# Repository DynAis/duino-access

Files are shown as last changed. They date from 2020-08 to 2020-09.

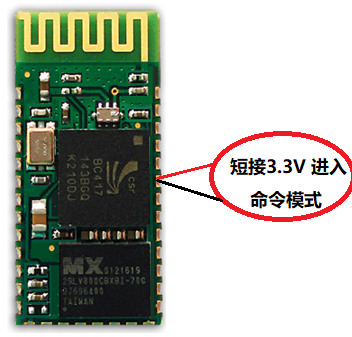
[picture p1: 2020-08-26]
doc/XM-04-HID蓝牙HID模块/命令模式.png

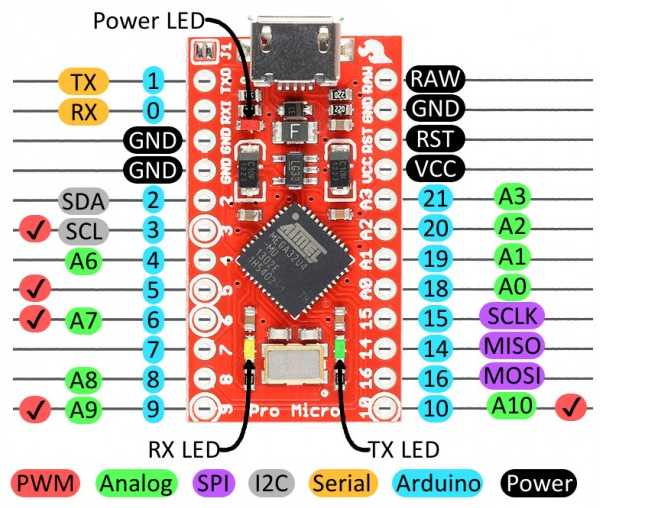
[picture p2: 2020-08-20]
doc/Arduino-Pro-Micro/引脚图.jpg

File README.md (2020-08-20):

# duino-access
 arduino based finger-print access system 

## 后续开发

### 库HN610

| 文件名 | 内容 |
| --- | --- |
| auth | 通讯签名算法(默认不签名) |
| fp | 大部分能直接用的API |
| fpmComm | 模块命令API |
| hzDevice  | 串口通信底层 |
| pinDef | 主板引脚定义 |
| hzTypes | 数据类型定义 |

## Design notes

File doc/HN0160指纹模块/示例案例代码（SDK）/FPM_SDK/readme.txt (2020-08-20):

####################################
#### HOZONOVO ALL RIGHTS RESERVED ####
####################################

fpmSDK implement note:

essential files need to be implemented:
fpmComm.c
fpmComm.h
hzTypes.h
hzDevice.c
hzDevice.h

Only 4 functions (in hzDevice) required to implement the protocol:

1)void write(const UINT8 *data, UINT32 len);	//send out data through UART port

2)UINT8 receive(UINT8 *data, UINT32 *len);	//receive data from fpm with UART

3)UINT32 getEndTime(UINT32 time);	//gets the expected ending timer tick in ms unit

4)UINT32 getCurTime(void);	//gets the current timer tick in ms unit

If bidirectional signature verification is required, there is another function that needs to be implemented:
5）void genRandom(UINT8 *ramdom,UINT8 len) // gen random number for signature

referenece files to realize the basic fingerprint functions:
fp.c
fp.h

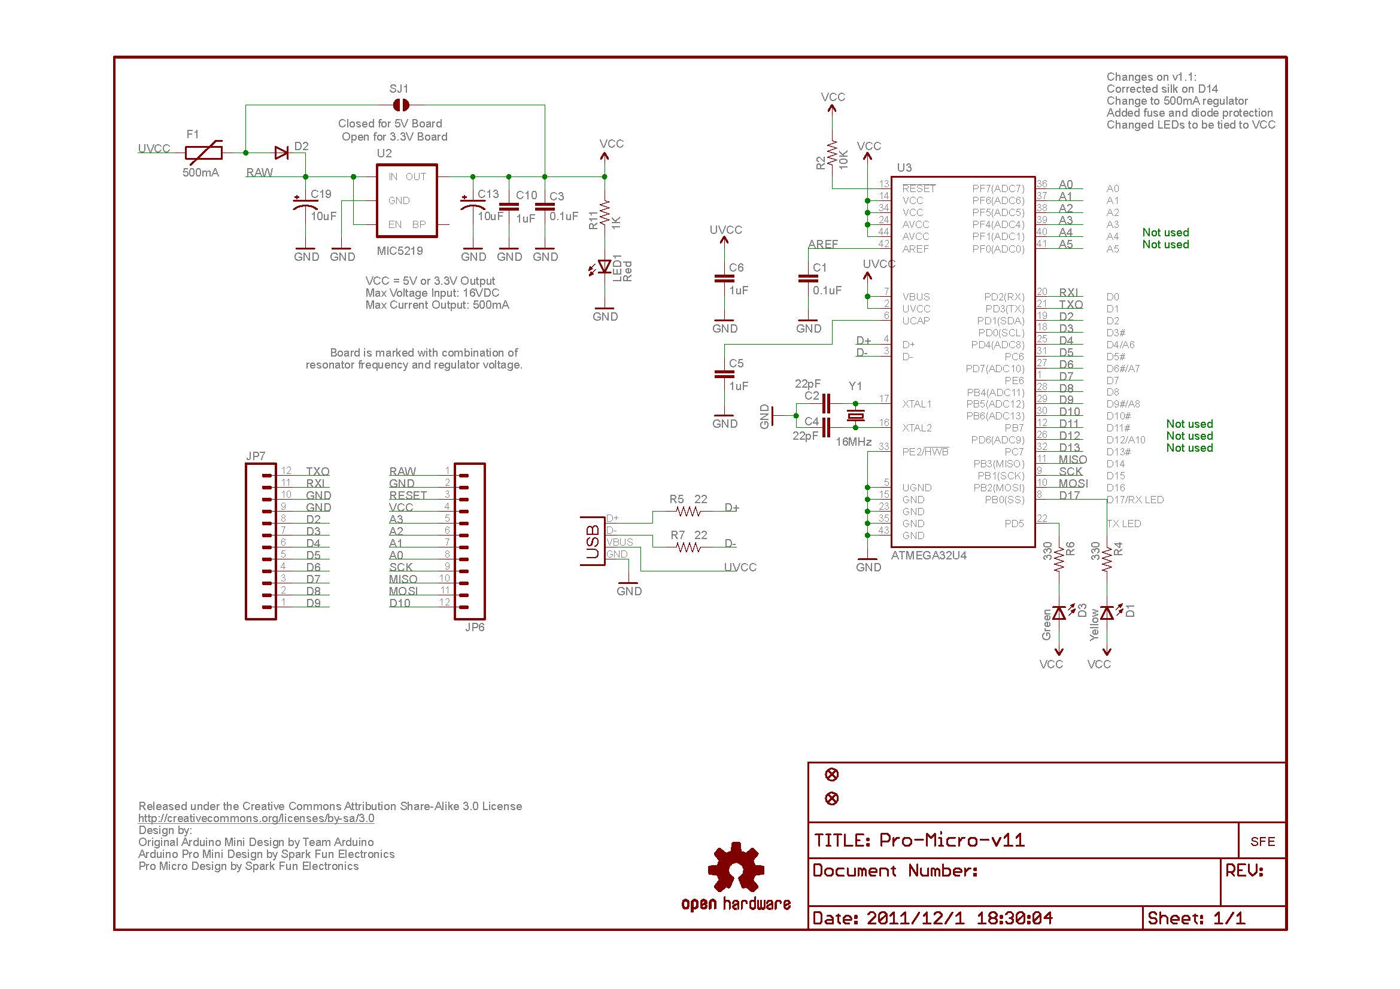
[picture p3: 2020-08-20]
doc/Arduino-Pro-Micro/Pro-Micro-原理图.jpg

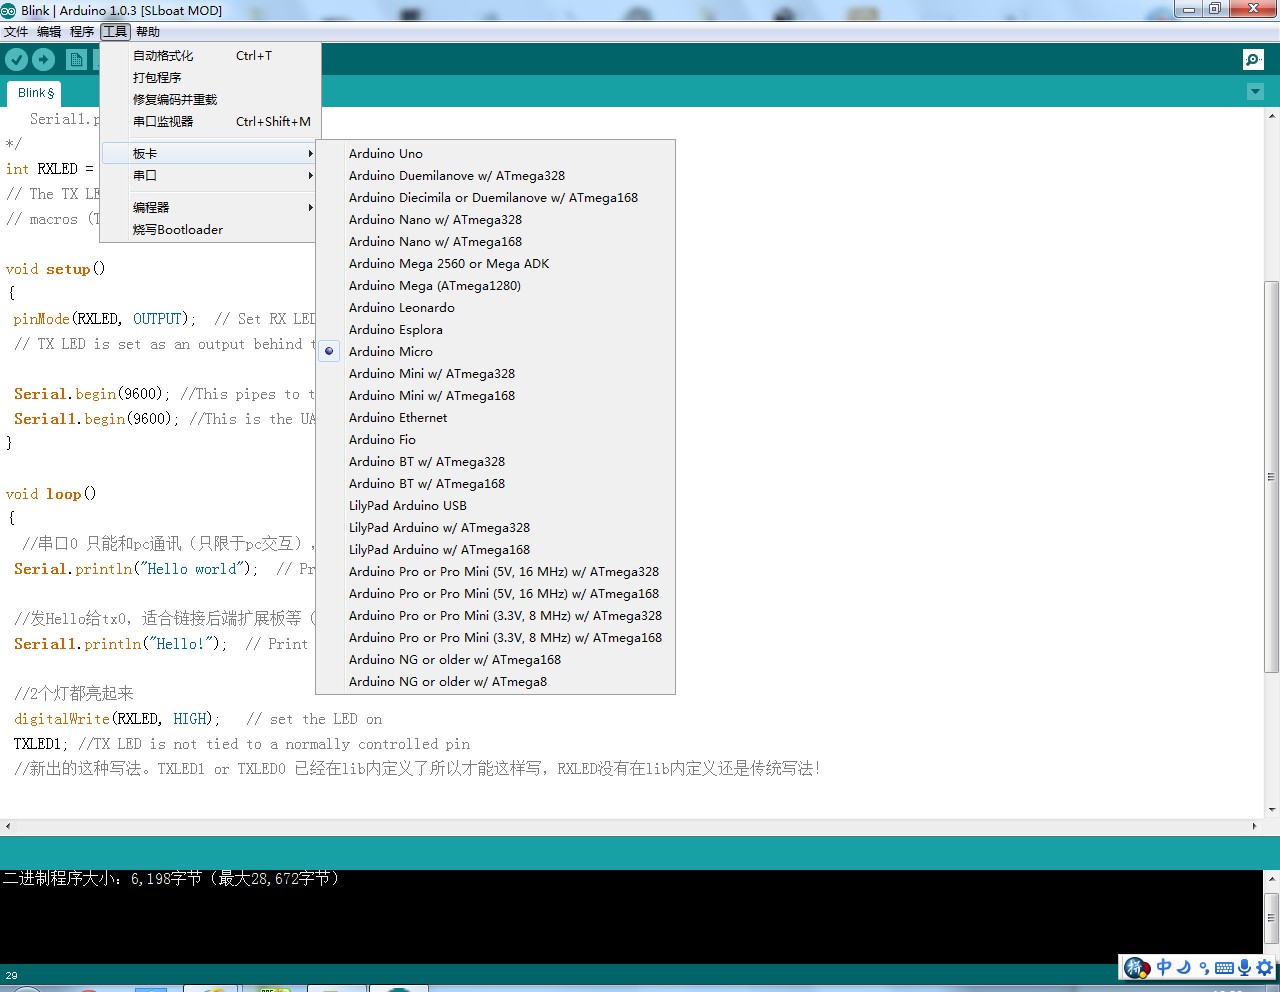
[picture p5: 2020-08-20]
doc/Arduino-Pro-Micro/驱动安装完成后，IDE里面board选micro.JPG

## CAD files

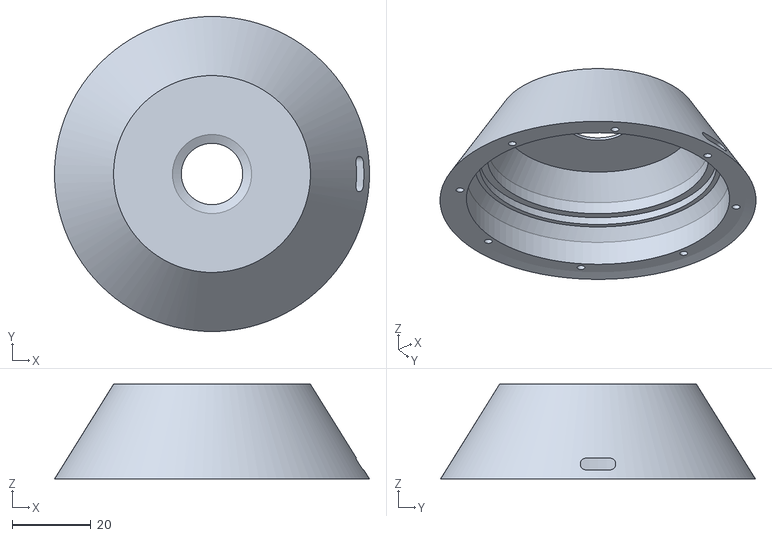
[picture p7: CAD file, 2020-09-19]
3dmodels/case/上半.stl
80.0 x 80.0 x 24.1

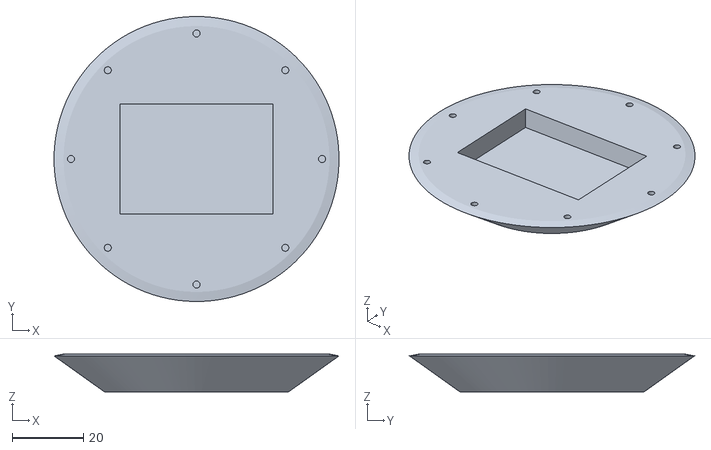
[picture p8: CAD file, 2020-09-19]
3dmodels/case/下半.stl
80.0 x 80.0 x 10.6

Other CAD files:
doc/TJDZ-RC522射频卡/51读写卡参考例程及上位机调试软件/51读写卡程序/MAIN.OBJ
doc/TJDZ-RC522射频卡/相关数据手册和参考文献/参考DEMO源代码/C51/MAIN.OBJ
doc/TJDZ-RC522射频卡/51读写卡参考例程及上位机调试软件/51读写卡程序/RC522.OBJ
doc/TJDZ-RC522射频卡/相关数据手册和参考文献/参考DEMO源代码/C51/RC522.OBJ
3dmodels/case/case.blend

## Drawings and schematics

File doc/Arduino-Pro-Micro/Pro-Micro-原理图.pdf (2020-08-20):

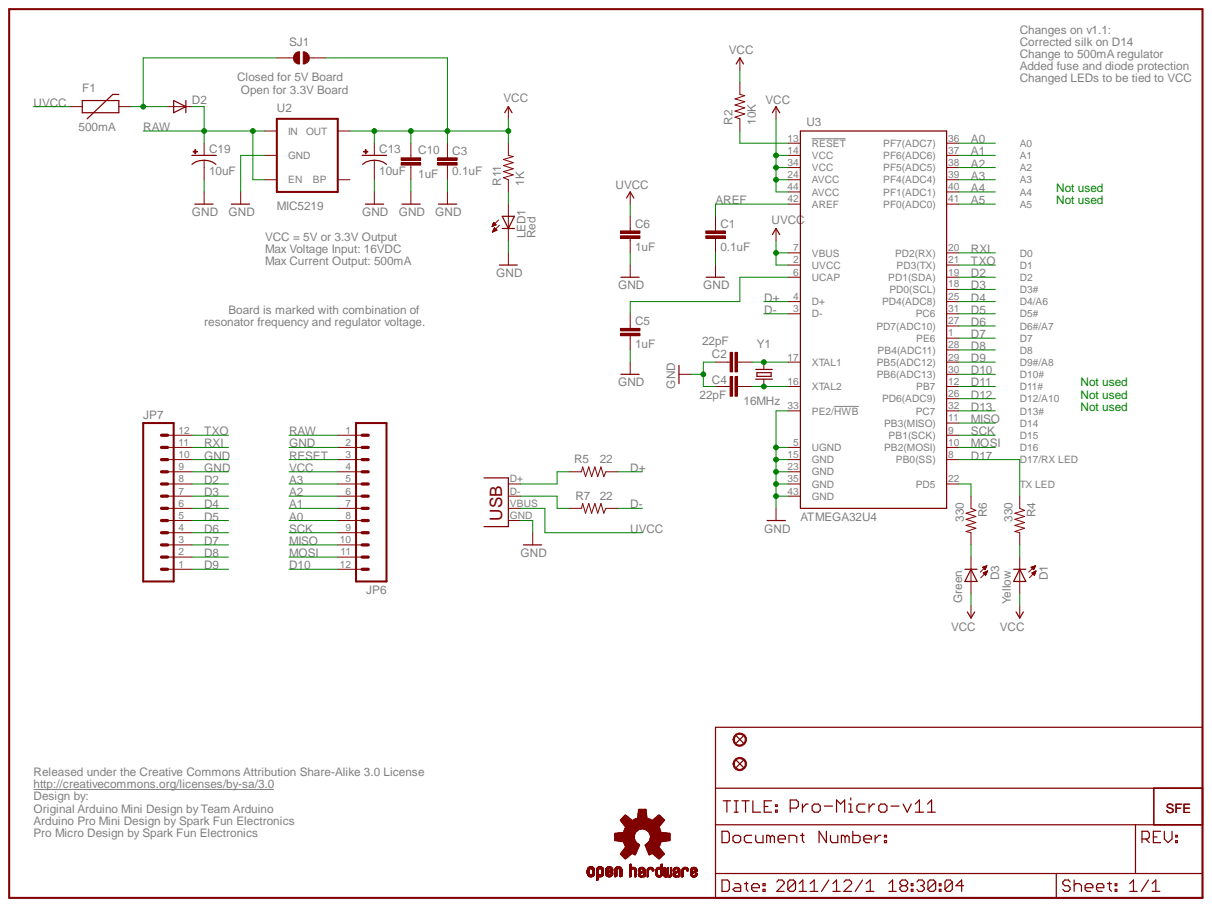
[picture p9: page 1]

Changes on v1.1:
Corrected silk on D14
Change to 500mA regulator
Added fuse and diode protection
Changed LEDs to be tied to VCC

Board is marked with combination of
resonator frequency and regulator voltage.

Released under the Creative Commons Attribution Share-Alike 3.0 License
http://creativecommons.org/licenses/by-sa/3.0
Design by:
Original Arduino Mini Design by Team Arduino
Arduino Pro Mini Design by Spark Fun Electronics
Pro Micro Design by Spark Fun Electronics

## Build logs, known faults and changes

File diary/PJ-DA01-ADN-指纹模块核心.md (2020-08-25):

[toc]

---

## 0x00 - 前言

这次也是因为闲的在家没有事情做，所以又给自己开了一个新坑，其实蛮早以前就有过想做一个电脑上能用的指纹锁的想法了，但是一直没有动手，刚好这次有机会，并且也是刚刚新组了一台电脑，就想着要把这个项目给做了。

这个项目的一个主要的灵感来源是@[稚晖君](https://space.bilibili.com/20259914/dynamic)很早以前发在Arduino论坛上的一个项目 ([Link: 如何制作一个带指纹识别的机械键盘](https://www.arduino.cn/thread-86889-1-3.html)), 这次项目的的主要思路都和他的差不多，只不过我想做成独立的一个模块，并且最好能够实现便携功能，也就是说如果可以的话我想加上蓝牙的功能

然后这次的文章大概也会写好几部分，具体取决于我最后能不能最后好好完成这个项目...

## 0x01 - 核心部分元器件选型

这次的目标是能够使用指纹解锁的方式让电脑自动解锁，思路是使用指纹模块给出信号+单片机模拟键盘输入的简单思路，由于整体的体积要求越小越好，所以元件的选型基本没有选择

| 使用模块 | 价格 |
| --- | --- |
| arduino-pro-micro (VCC 5v or 3.3v) | 19.80 CNY |
| HN0610 指纹模块 | 45.00 CNY |
| AMS1117-3.3v/5v 降压模块 (假如使用5v的arduino，3.3v的不需要) | 1.29 CNY  |
| 蜂鸣器、导线若干 | - |

之所以没有用稚晖的那个FPM3X指纹模块的原因是因为那个好像在TB上已经快找不到了，只剩下最后一家而且卖的很贵，所以当时就选择了这个卖得最好的来做(有几天自闭的时候非常后悔这个选择)，并且从外观上来说我更喜欢这款一点

## 0x02 - 环境选择与搭建

### VSCode + PlatformIO

整个环境方面没有使用传统的 ArduinoIDE 来做，而是选择的使用 VSCode 来完成这次的项目，主要原因是为了以后做其他单片机项目的时候也都统一到 VSCode上去，这样整个一致性会比较好

最后选择了 VSCode 的 PlatformIO 拓展



直接在 VSCode 的拓展商店里搜索即可，点击安装即可安装插件，不用动什么脑子，安装过程会有些慢需要耐心等待一会，安装完成后如果成功了你应该可以在左下角看到这个小图标



恭喜，如果你看到了这个小房子，那你基本就是安装成功了，但是由于各种各样的原因，你也很有可能等了半天他也还是在转圈圈加载，像我一样



那么大概率他是不能自己装上了，我们只能来手动安装

首先，如果你安装失败了，请先卸载原来的安装失败的 PlatformIO ，重启 VSCode，之后在VSCode的终端里输入

`pip --no-cache-dir install -U platformio`

等待他安装完成，重启VSCode，重新去商店点一下安装，就可以顺利的装上了

{% alert info %}

如果依旧不行，可以尝试: 移除Anaconda(假如你安装了Anaconda环境)、安装Python2.7版本并且添加进环境变量、安装Python最新版本并添加进环境变量，如果这也不行，那就尝试使用ArduinoIDE吧(不过这样也许需要稍微改动下代码)

{% endalert %}

### PlatformIO开发准备

点击Home按钮打开 PlatformIO 主界面，new project 后选择对应的板子，他会进行自动的初始化



初始化完成后，在src文件夹里就是我们的main文件



PlatformIO 和 ArduinoIDE 不同的地方就是，他是使用cpp文件来进行编译上传的，而不是ino文件，所以每个需要用到 Arduino 库的文件中，都需要包含`#include "Arduino.h"`才能够使用

此外，比较麻烦的一点是，对于某些库的支持，也是需要我们手动来加入的，比如这块 Pro Micro 支持的HID键盘和鼠标的功能，就需要我们手动加入

首先打开刚才的Home界面，在左边一栏里可以找到 Libraries



搜索`keyboard`，找到这个 Arduino 的官方库文件安装



安装完成以后，到左边的资源管理器，找到`platformio.ini`这个文件

在文件最后加入

```ini
lib_deps = 
    Keyboard
```

告诉他我们要调用这个库，这样就完成了，可以开始硬件部分的测试了

## 0x03 - 硬件部分

{% alert warning %}

一定要注意指纹模块的供电是3.3v，使用5v虽然不会烧坏模块但是会无法工作(当初因为这个原因卡了好久不知道哪错了)

{% endalert %}

指纹模块的话是线给剪了直接焊在了板子上，有点粗糙

（接线参照图）

看不清楚的话也可以看源文件里 `/lib/HN0610/pinDef.h` 里的内容

最后附上Micro的引脚图



### 测试指纹模块

修改 `/src/min.cpp` 文件中参数调整宏定义区域的参数  `DASTATE` 就可以设定当前运行在什么模式下，由于是测试，就把值改为0，运行在检测手指模式上，其他模式的定义也在下面给出

| 功能实现 | DASTATE值 |
| --- | --- |
| 检测手指按压 | 0 |
| 指纹注册 | 1 |
| 验证指纹(最后留这一个) | 2 |
| 检测手指按压后输出硬件信息(需要打开电脑串口) | 3 |
| 清除所有指纹信息 | 4 |

 点击上传烧录进Arduino

如果没有问题的话，按下手指蜂鸣器就会鸣响了

## 0x04 - 遇到的坑和问题

### 1. 底层数据类型定义问题

通常来说，开发单片机会定义一系列的UINT

在这次，定义文件写在了 `hzTypes.h` 文件里，其中对于UINT32的定义出现了兼容错误

原始内容是



我猜测可能是由于他们使用的单片机上int是32位，所以能够正常运行，而在Arduino上，int并不是32位的，long才是，所以需要改为



### 2.电源的坑

已经说过了，不过这次也是因为在家里没有万用表的缘故，并且提醒，虽然原理图上有一个SJ1来控制Micro的输出电压是5v还是3.3v，但是你并不可以通过连接或者断开这个引脚来达到修改电压的目的，因为5v的Micro和3.3v的Micro主频也是不一样的，这会导致工作不稳定

并且很有可能改了也没有作用(对于很多国产板)



### 3.注意Micro的中断脚

因为这个指纹识别模块还有自动休眠的功能，所以虽然我现在并没有使用，但是很有可能会用到这个模块的中断信号，那么就要注意Micro的中断引脚定义和Uno是不一样的

| PIN  | 中断号 |
| ---- | --- |
| 3 | 0 |
| 2 | 1 |
| 0 | 2 |
| 1 | 3 |
| 7 | 6 |

## 0x05 - 后续开发

### 库HN610

| 文件名 | 内容 |
| --- | --- |
| auth | 通讯签名算法(默认不签名) |
| fp | 大部分能直接用的API |
| fpmComm | 模块命令API |
| hzDevice  | 串口通信底层 |
| pinDef | 主板引脚定义 |
| hzTypes | 数据类型定义 |

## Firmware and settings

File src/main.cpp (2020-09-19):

/* DuinoAccess-MainCode
   by: Dynais
   date: 2020-08-14
   messages: 修改下方参数调整区域内的宏定义达到基本的参数调整
*/

//头文件
#include "DAinclude.h"
#include "DAstate.h"
#include <avr/sleep.h>

//参数调整
#define PASSWORD "44687E64A8E2557DF7CFA83C989A4627" //在这里填上你的密码
#define DETECT_PAUSE 2000                           //连续检测间隔 (ms)(只作用于身份验证模块)
#define ARDUINO_BAUD 115200                         //Arduino USB串口通信波特率
#define DASTATE 2                                   //调整参数以更改整体功能

extern UINT8 sigState; //信号灯标志位
extern CRGB signal_leds[];
extern UINT8 fpState;    //指纹检测标志位
UINT8 prevFpState;       //前一次指纹检测标志位
UINT8 retval;            //返回信息标志位
UINT8 prevRetval;        //前一次返回信息标志位
volatile bool ifFpAwake; //休眠标志位

//指示灯光定时器中断处理
void sigProcess()
{
  //灯光处理
  updateSignal(sigState);
}

//指纹模块唤醒外部中断处理
void fpAwake()
{
  ifFpAwake = true;
  // sleep_disable();
  // detachInterrupt(digitalPinToInterrupt(7));
}

//串口输出指纹模块信息
void getFpInfo()
{
  ST_DEV_INFO_HOZO info;
  retval = fpmGetDeviceInfo(&info);
  Serial.print("当前波特率: ");
  Serial.println(info.baudrate);
  Serial.print("当前已注册指纹量: ");
  Serial.println(info.enrollCount);
  Serial.print("总指纹容纳量: ");
  Serial.println(info.maxCount);
  Serial.print("当前设备签名信息: ");
  Serial.println(info.signature);
  Serial.print("指纹采样数量: ");
  Serial.println(info.sampleSize);
  Serial.print("指纹识别门槛等级: ");
  Serial.println(info.matchingThreshold);
  Serial.print("指纹唯一性限制: ");
  Serial.println(info.uniqueConstrain);
  Serial.print("指纹严格模式: ");
  Serial.println(info.strictEnrollment);
}

//初始化
static void initialize()
{
  //引脚初始化
  pinMode(PIN_FP_RST, OUTPUT);
  pinMode(7, INPUT);

  //串口初始化
  Serial.begin(ARDUINO_BAUD); //This pipes to the serial monitor
  Serial1.begin(57600);       //This is the UART, pipes to sensors attached to board
  delay(500);

  //WS2812灯光初始化
  sigInit();

  //定时器中断初始化
  MsTimer2::set(16, sigProcess);
  //开始计时
  MsTimer2::start();

  //指纹模块初始化
  Serial.println("in Init");
  while (fpInit())
  {
    Serial.println(fpInit(), HEX);
    sigState = SIG_STATE_FAILED;
    debug();
  }

  //唤醒指纹模块
  Serial.println("in WakeUP");
  while (fpWakeup())
  {
    Serial.println(fpWakeup(), HEX);
    sigState = SIG_STATE_FAILED;
    debug();
  }
  ifFpAwake = true;

  //外部中断初始化
  attachInterrupt(digitalPinToInterrupt(7), fpAwake, RISING);

  //蓝牙模块初始化
  btInit();

  //USB检测
  USBCON|=(1<<OTGPADE); //enables VBUS pad
}

void setup()
{
  initialize();
  success();
  sigState = SIG_STATE_SUCCESS;
  delay(1000);
  sigState = SIG_STATE_SLEEP;
  Serial.print("DASTATE : ");
  Serial.println(DASTATE);
}

void loop()
{

  switch (DASTATE)
  {

    //******************************************************************//
    //  usage：用于测试硬件的完好性
    //  signal：检测到有手指时，亮绿灯，没有手指时不亮灯
    //
    //******************************************************************//
  case DA_STATE_PRESSTEST:
  {
    //检测手指
    retval = fpmDetectFinger(NULL);
    //通过对比前一次指纹探测状态是否跳变来控制灯光标志位的变化
    if (prevRetval == HZERR_NO_FINGER && retval == HZERR_SUCCESS)
    {
      sigState = SIG_STATE_SUCCESS;
      // btSendPassworld(PASSWORD);
    }
    else if (retval == HZERR_NO_FINGER && prevRetval == HZERR_SUCCESS)
    {
      sigState = SIG_STATE_SLEEP;
    }
    //结束后重新复制
    prevRetval = retval;
    delay(100);
    break;
  }
    //******************************************************************//
    //  usage：用于写入指纹到指纹模块
    //  signal：等待黄灯亮起，示意等待手指接触，接触后亮蓝灯表示检测到手指
    //          如果手指长时间未移开，亮橙色灯示意，成功完成一次录入亮绿灯，重复
    //******************************************************************//

  case DA_STATE_ENROLL:
  {
    // Serial.println("--- start enroll finger ---");
    fpState = FP_STATE_START;
    sigState = SIG_STATE_SLEEP;
    //设置指纹过长防止提醒时间
    UINT32 warningPressTime;
    delay(2000);
    //进入注册循环
    while (1)
    {
      prevFpState = fpState; //保存前一次状态
      // Serial.println("in fpenroll");
      fpEnroll();

      // 根据指纹标志位来判断当前状态
      switch (fpState)
      {
      case FP_STATE_WAIT_FINGER_OFF2ENROLL:
      case FP_STATE_WAIT_FINGER_OFF2OK:
      case FP_STATE_WAIT_FINGER_OFF2ERR:
        if (FP_STATE_ENROLL_PROC == prevFpState)
        {
          // Serial.println("--- please release your finger ---");
          if (prevFpState != fpState)
            //状态转换时记录一次时间，用来判断手指过长时间放置
            warningPressTime = getEndTime(3000);
          sigState = SIG_STATE_PROCESSING;
        }
        if (warningPressTime < getCurTime() && sigState != SIG_STATE_WARNING)
          sigState = SIG_STATE_WARNING;
        break;
      case FP_STATE_END_OK:
        // Serial.println("--- enroll sucess ---");
        sigState = SIG_STATE_SUCCESS;
        delay(1000);
        break;
      case FP_STATE_END_ERR:
        // Serial.println("--- enroll failed ---");
        sigState = SIG_STATE_FAILED;
        delay(1000);
        break;
      default:
        if (prevFpState != fpState)
          sigState = SIG_STATE_WAITTING;
        break;
      }
      //一次指纹录入结束
      if (FP_STATE_DEFAULT == fpState)
      {
        if (prevFpState != fpState)
          sigState = SIG_STATE_WAITTING;
        break;
      }
      //查看录入状态
      // Serial.print(getCurTime());
      // Serial.print(" ");
      // Serial.print(warningPressTime);
      // Serial.print(" ");
      // Serial.println(sigState);
    }
    break;
  }
    //******************************************************************//
    //  usage：身份验证，用于最后使用，需要先录入指纹，有休眠
    //  signal：不适用时呈休眠状态不亮灯，检测到手指并且验证成功时亮绿灯，否则
    //          亮红灯
    //******************************************************************//

  case DA_STATE_DETECT:
  {
    UINT32 cdEndTime = getCurTime();
    UINT32 awakeEndTime = getEndTime(30000);
    while (1)
    {
      if (ifFpAwake) //只有指纹模块不休眠的时候才进入验证
      {
        retval = fpIdentify(); //身份验证
        //验证成功
        if (HZERR_SUCCESS == retval)
        {
          sigState = SIG_STATE_SUCCESS;
          //两次成功的验证之间不得小于指定时间
          if (cdEndTime < getCurTime())
          {
            if(USBSTA&(1<<VBUS)){  //checks state of VBUS
              Keyboard.begin();
              Keyboard.println(PASSWORD);
              Keyboard.end();
            }
            else{
              btSendPassworld(PASSWORD);
            }
            // Serial.println("--- identify successed ---");
            cdEndTime = getEndTime(DETECT_PAUSE);
          }
          fpUpdate();                       //完善指纹数据
          awakeEndTime = getEndTime(30000); //识别到指纹就刷新休眠倒计时
        }
        //验证失败
        else if (HZERR_NO_FINGER != retval)
        {
          sigState = SIG_STATE_FAILED;
          // Serial.println("--- identify failed ---");
          awakeEndTime = getEndTime(30000); //识别到指纹就刷新休眠倒计时
        }
        //灯光休眠
        else
        {
          sigState = SIG_STATE_SLEEP;
        }

        //30s没有检测到手指指纹模块就进入休眠
        if (awakeEndTime < getCurTime() && ifFpAwake)
        {
          //指纹模块休眠
          fpmSetSleepMode(0x03, NULL);
          ifFpAwake = false;
          // //Arduino休眠
          // set_sleep_mode(SLEEP_MODE_PWR_DOWN);
          // delay(500);
          // // sleep_cpu();
          // sleep_mode();
        }
      }
    }
    break;
  }
    //******************************************************************//
    //  usage：查看硬件信息,使用时需要配合指纹模块摁手指才能输出到串口
    //  signal：无
    //******************************************************************//

  case DA_STATE_GETINFO:
  {
    retval = fpmDetectFinger(NULL);
    if (retval == HZERR_SUCCESS)
    {
      sigState = SIG_STATE_SUCCESS;
      getFpInfo();
      delay(2000);
    }
    sigState = SIG_STATE_SLEEP;
    delay(2000);
    break;
  }
    //******************************************************************//
    //  usage：清除指纹数据库
    //  signal：无
    //******************************************************************//

  case DA_STATE_CLEAR: //清除所有指纹信息功能
  {
    delay(2000);
    retval = fpDeleteAll();
    Serial.print("尝试清除所有指纹信息: ");
    Serial.println(retval);
    getFpInfo();
    while (1)
      ;
    break;
  }
    //******************************************************************//
    //  usage：配置指纹模块参数
    //  signal：亮绿灯表示配置参数成功，反之亮红灯
    //******************************************************************//

  case DA_STATE_SETPARAM:
  {
    retval = fpmDetectFinger(NULL);
    if (retval == HZERR_SUCCESS)
    {
      // UINT32 param;
      // fpmGetParam(&param, NULL);
      // fpmSetParam(param,NULL);
      // // Serial.println(param, HEX);
      // // delay(100);
      // // // Serial1.end();
      // // // Serial1.begin(115200);
      // // delay(100);
      // getFpInfo();

      sigState = SIG_STATE_SUCCESS;
      delay(2000);
    }
    sigState = SIG_STATE_SLEEP;
    break;
  }
    //******************************************************************//
    //  usage：无
    //  signal：无
    //******************************************************************//
  default:
    debug();
    sigState = SIG_STATE_WARNING;
    delay(5000);
    break;
  }
}

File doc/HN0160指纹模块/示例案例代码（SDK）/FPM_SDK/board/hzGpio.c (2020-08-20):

#include "hzGpio.h"

void gpioCfgPin(UINT32 pin, GPIO_DIR dir, GPIO_PULL pull)
{
    Gpio_InitIOExt((UINT8)(pin >> 16), (UINT8)pin, (en_gpio_dir_t)dir, (pull == PULL_UP), (pull == PULL_DOWN), FALSE, FALSE);
}

void gpioSetPin(UINT32 pin)
{
    UINT8 port, offset;
    UINT32 addr;

    port = (UINT8)(pin >> 16);
    offset = (UINT8)(pin & 0x000000ff);
    addr = (UINT32)&M0P_GPIO->P0OUT + port * GPIO_GPSZ;
    *((volatile UINT32 *)(addr)) |= ((1UL)<<(offset));
}

void gpioClrPin(UINT32 pin)
{
    UINT8 port, offset;
    UINT32 addr;

    port = (UINT8)(pin >> 16);
    offset = (UINT8)(pin & 0x000000ff);
    addr = (UINT32)&M0P_GPIO->P0OUT + port * GPIO_GPSZ;
    *((volatile UINT32 *)(addr)) &= (~(1UL<<(offset)));
}

void gpioTglPin(UINT32 pin)
{
    UINT8 port, offset;
    UINT32 addr;

    port = (UINT8)(pin >> 16);
    offset = (UINT8)(pin & 0x000000ff);
    addr = (UINT32)&M0P_GPIO->P0OUT + port * GPIO_GPSZ;
    *((volatile UINT32 *)(addr)) ^= ((1UL)<<(offset));
}

UINT32 gpioGetPin(UINT32 pin)
{
    return (UINT32)Gpio_GetIO((UINT8)(pin >> 16), (UINT8)pin);
}

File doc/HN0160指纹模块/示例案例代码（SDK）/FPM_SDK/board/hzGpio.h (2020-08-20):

#ifndef _HZ_GPIO_H_
#define _HZ_GPIO_H_

#include "hzTypes.h"
#include "gpio.h"

#define PORT0           0x00000000UL
#define PORT1           0x00010000UL
#define PORT2           0x00020000UL
#define PORT3           0x00030000UL
#define PORT4           0x00040000UL
#define PORT5           0x00050000UL
#define PORT6           0x00060000UL
#define PORT7           0x00070000UL

#define PIN00           0x00000000UL
#define PIN01           0x00000001UL
#define PIN02           0x00000002UL
#define PIN03           0x00000003UL
#define PIN04           0x00000004UL
#define PIN05           0x00000005UL
#define PIN06           0x00000006UL
#define PIN07           0x00000007UL
#define PIN08           0x00000008UL
#define PIN09           0x00000009UL
#define PIN10           0x0000000AUL
#define PIN11           0x0000000BUL
#define PIN12           0x0000000CUL
#define PIN13           0x0000000DUL
#define PIN14           0x0000000EUL
#define PIN15           0x0000000FUL


#define PIN_FP_INT      (PORT3 | PIN05)
#define PIN_FP_RST      (PORT3 | PIN06)
#define PIN_CHRG_DET    (PORT2 | PIN05)
#define PIN_LED_R       (PORT1 | PIN05)
#define PIN_LED_G       (PORT2 | PIN03)
#define PIN_LED_B       (PORT2 | PIN04)
#define PIN_MT_IN1      (PORT3 | PIN03)
#define PIN_MT_IN2      (PORT3 | PIN04)
#define PIN_MT_DET      (PORT3 | PIN02)

#define PIN_NONE        0xFFFFFFFFUL


/**
 * Enumeration type for the dirction of GPIO pad on a given pin.
 */
typedef enum {
    OUT,      /**< OUTPUT */
    IN,       /**< INPUT */
}GPIO_DIR;

/**
 * Enumeration type for the type of GPIO pad on a given pin.
 */
typedef enum {
    PULL_NONE,     /**< No pull-up or pull-down */
    PULL_UP,       /**< Set pad to weak pull-up */
    PULL_DOWN,     /**< Set pad to weak pull-down */
}GPIO_PULL;

void gpioCfgPin(UINT32 pin, GPIO_DIR dir, GPIO_PULL pull);
void gpioSetPin(UINT32 pin);
void gpioClrPin(UINT32 pin);
void gpioTglPin(UINT32 pin);
UINT32 gpioGetPin(UINT32 pin);

#endif

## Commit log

2020-08-20 核心模块开发完成
    - 易用性、规范性升级
2020-08-25 加入ws2182灯光模块
    - 响应及时性待修改
    [MAIN.OBJ, Package1.cfg, RC522.OBJ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]
2020-08-25 增强灯效交互实时性
2020-08-25 灯光模块基本功能建设完毕
    - 加强了灯光互动时效性
    - 完善了代码规范
2020-08-25 完善代码规范
2020-08-26 指纹模块加入休眠功能
    [MAIN.OBJ, Package1.cfg, RC522.OBJ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]
2020-08-26 蓝牙模块初步建设完成
2020-09-19 版本发布v0.1
    [case.blend, 上半.stl, 下半.stl]
